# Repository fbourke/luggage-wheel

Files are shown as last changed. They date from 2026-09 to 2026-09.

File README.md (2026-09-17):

# luggage-wheel

Replacement dual-wheel spinner carriage for Rimowa-style luggage: CNC
aluminium body swivelling on the case's Ø10 shaft (needle thrust bearing +
Oilite bushing) and a through-axle carrying two wheels. The original wheels
ran on plain plastic bores and wore out.

Two wheel variants share the body (`WHEEL_SOURCE` env var, default `ots`):
**`ots`** uses bought Ø50 × 12 PU luggage wheels on a Ø6 axle (see
[`docs/wheel_sourcing.md`](docs/wheel_sourcing.md)); **`machined`** is our
turned Al hub on 688 bearings with printed TPU tires, kept as a fallback.

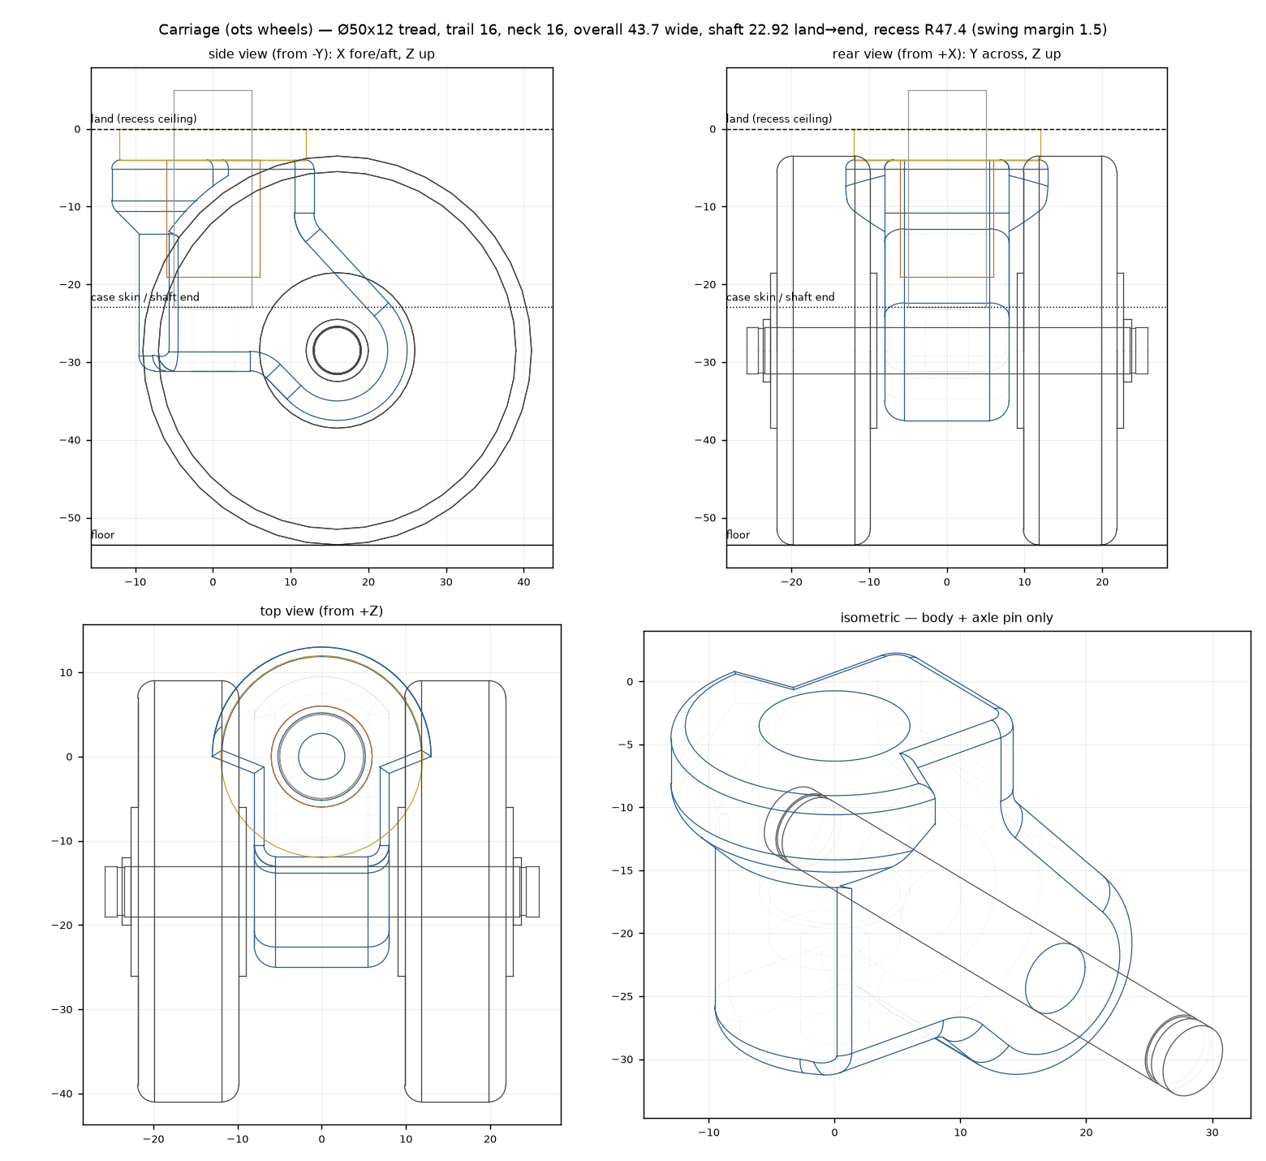
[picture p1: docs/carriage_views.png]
carriage


- [`docs/design.md`](docs/design.md) — envelope, swivel, axle, machinist tolerances, print settings, open questions
- [`docs/wheel_sourcing.md`](docs/wheel_sourcing.md) — off-the-shelf wheel research (Floyd, generic 50×12, Rimowa OEM…)
- [`bom.md`](bom.md) — parts, quantities, sources
- [`cad/params.py`](cad/params.py) — every dimension, single source of truth
- [`cad/wheel.py`](cad/wheel.py), [`cad/carriage.py`](cad/carriage.py) — build123d models
- [`cad/generate.py`](cad/generate.py) — exports + clearance report
- [`cad/preview.py`](cad/preview.py), [`cad/views.py`](cad/views.py) — PNG renders

## Regenerate

Dependencies are managed with [uv](https://docs.astral.sh/uv/).

```sh
uv run cad/generate.py                        # ots: STEP + STL into export/, clearance report
uv run cad/views.py                           # docs/carriage_views.png
WHEEL_SOURCE=machined uv run cad/generate.py  # fallback variant into export/machined/
WHEEL_SOURCE=machined uv run cad/views.py     # docs/carriage_views_machined.png
uv run cad/preview.py                         # docs/cross_section.png (machined wheel)
```

## Outputs

| File | Use |
|---|---|
| `export/body.step`, `axle_pin.step`, `ots_spacer.step` | to the CNC shop, with the tolerance tables in `docs/design.md` |
| `export/ots_wheel_ref.step` | dummy of the bought wheel, for reference |
| `export/carriage_fit_proto.stl` | **one-piece printed fit-check**: body + thrust collar + solid wheels; screws straight onto the case with the existing M5 bolt |
| `export/body_proto.stl` | printed body for bushing/axle fit checks |
| `export/carriage_assembly.step` | full assembly with dummy wheels, for viewing |
| `export/machined/…` | the same set for the machined-wheel variant, plus `hub.step`, `spacer.step`, `tire.step`/`.stl`, `wheel_assembly.step` |

STL files are not committed (regenerate them); STEP files are.

## Status

Envelope fully measured; a printed one-piece proto **fits the recess, pivots
freely and matches the OEM ride height**. Direction is now bought Ø50 × 12
wheels on the machined body. Next: buy a pack, measure them, print
`body_proto.stl`, then order metal. Open questions are in `docs/design.md`.

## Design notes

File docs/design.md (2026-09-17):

# Replacement spinner carriage — design notes

Replacement for a failed dual-wheel spinner carriage (Rimowa-style knockoff):
the whole unit that bolts onto the case's Ø10 swivel shaft and carries two
Ø50 × ~12 mm wheels. The original's wheels ran on plain plastic bores, which
wore out.

carriage

## Two wheel variants, one body

`params.py` has a `WHEEL_SOURCE` switch (environment variable; default `ots`):

- **`ots`** — off-the-shelf Ø50 × 12 dual-spinner luggage wheels (PU tread,
  plastic hub, one Ø6-bore ball bearing, 13.7 over the hub bosses; ~$2.50
  each in 8-packs). Ø6 axle, trail 16. **This is the plan** — see
  [`wheel_sourcing.md`](wheel_sourcing.md) for the research.
- **`machined`** — our turned Al hub on 2× 688 with a printed TPU tire. Ø8
  axle, trail 18.1. Kept as the fallback if the bought wheels disappoint;
  builds into `export/machined/`.

The body is the same part except for the axle bore (Ø6 vs Ø8) and its
position (trail). Everything below applies to both unless it says otherwise;
the "Wheel" chapter is the machined variant.

## Architecture (`ots`)

| Part | Material | Made by | Qty / carriage |
|---|---|---|---|
| Body | Al 6061-T6 | outsourced CNC (3-axis milled) | 1 |
| Axle pin | Ø6 h6 ground steel shaft, 51.6 long, 2 circlip grooves | cut + grooved, or CNC order | 1 |
| Circlip | DIN 471 Ø6 | purchased | 2 |
| Wheel | generic Ø50 × 12 PU luggage wheel, Ø6 bearing | purchased, 8-pack | 2 |
| Inboard spacer bush | Ø8 / Ø6.1 × 1.0, steel or Al (kits include similar) | kit / turned / printed | 2 |
| Outboard ring | steel 6×10×0.5 washer | purchased | 2 |
| Swivel thrust bearing | AXK1024 needle thrust + 2× AS1024 washers | purchased | 1 set |
| Swivel bushing | Oilite SAE 841, 10×12×15 | purchased | 1 |
| Retention bolt | existing M5 button head, 19 under head — bears directly on the body | reuse | 1 |

For `machined` swap the wheel rows for: Ø8 axle pin 46.4 long, DIN 471 Ø8
circlips, 2× Al hub, 4× 688-2RS, 2× Al spacer ring, 4× 8×12×0.5 speed rings,
2× TPU tire.

Everything is parametrised in [`cad/params.py`](../cad/params.py); regenerate
with `uv run cad/generate.py`.

## Coordinate frame

`X` fore/aft with the shaft axis at X = 0 and the wheels at X = +TRAIL (16 for
`ots`, 18.1 for `machined`);
`Y` across; `Z` up with **Z = 0 at the land** — the raised plastic face at the
ceiling of the corner recess that the swivel bears on. The case's bottom skin
is at Z = −22.92, flush with the shaft end; floor at Z = −53.5.

## Envelope — why the body looks the way it does

Each corner of the case has a **quarter-circle recess**, ~47.4 mm radius about
the shaft axis and 22.9 mm deep. The Ø10 shaft hangs from the recess ceiling
and ends flush with the case skin, so the whole shaft, the swivel, and the
upper 19 mm of the wheels live inside the recess; the wheels stick out ~30 mm
below the skin. Measured: land → floor 53.5, so **the wheel top is 3.5 mm
below the land** and the axle is 28.5 mm down. Consequences:

- Nothing can sit above the wheels. Everything that spans wider than the
  **16 mm neck** (wheel gap 17 − 2 × 0.5) has to be in front of the wheel
  circle or sculpted to it.
- **Swivel boss** — a "cap" of revolution about the shaft axis: **Ø26 for the
  top 6 mm** (the band that backs the Ø24 thrust washer), a **45° cone** down
  to a **Ø19 stem** around the bore, running to the **flat at Z −24.6** that
  the bolt head bears on. In plan the cap is a half-round in front, tapering
  into the neck 2 mm behind the axis. The stem gives 3.5 mm of wall over the
  Ø12 bushing bore and encloses the shaft end. Wherever the boss overhangs the
  wheels (|Y| > 8) it is scooped to a cylinder 1.5 mm outside the tire — this
  trims the cap rim ("ears") and cuts the stem flush with the neck faces where
  the wheels pass. Rounds: R2 on the cap underside edge, R1.5 on the top
  perimeter, R2 on the cap corners.
- **Arm**: in side view, a Ø18 round about the axle joined to the boss by two
  tangent lines — one from the boss rear at Z −12 (nothing above it), one from
  the flat just behind the bolt head. Nothing sits under the bolt head.
- The whole body is inside the recess above the skin plane (max 27 mm from
  the axis; the wall is at 47).
- **Width is capped by the recess wall.** The farthest point from the swivel
  axis is the outer tread edge where the wheel crosses the skin plane; the
  original (16.63 gap, 11.5 wheels) swings at R 46.86 against a ~47.4 wall.
  Width and trail trade off against each other: `machined` keeps 11.5 mm
  wheels at the original 18.1 trail (swing R 46.86, overall 39.6); `ots`
  wheels are 13.7 over the bosses so the trail drops to 16.0, which brings the
  swing radius *in* to 45.9 (overall 43.7). `params.py` asserts the swing
  radius never exceeds the original's.

`generate.py` prints an analytic clearance report (thrust washer ↔ tire, neck
↔ tire, wheel swing ↔ recess wall, body and bolt head ↔ floor). Check it
after every parameter change.

## Swivel

The Ø10 (measured 9.82) shaft is fixed to the case; the body rotates on it and
the case's weight bears on the Ø20.4 plastic land molded around the shaft,
with radial ribs at the same height.

**Thrust — AXK1024 needle roller thrust bearing (10×24×2) between two AS1024
hardened washers (10×24×1)**, 4 mm total, between the land and the body's top
face. The upper washer is stationary against the plastic, the lower one turns
with the body, needles between. The Ø24 washer overhangs the Ø20.4 land by
1.8 mm but sits on the ribs there, and spreads the load on the plastic far
better than the old body did.

**Radial — Oilite bronze sleeve bushing 10×12×15**, pressed into a Ø12 H7 bore
from the top, flush with the top face. A swivel turns a few degrees at near
zero speed under moderate load: that is textbook sintered-bronze territory, and
no ball bearing with a Ø10 bore fits inside an 18 mm neck anyway (6800 is
Ø19 OD). Shaft finish matters more than the bushing: if the shaft is rough or
plated-and-chipped, polish it.

**Retention** — OEM style, closed bore, **position-controlled by the bolt
bottoming out**. Measured: the existing M5 × 19 button head bottoms in the
shaft's blind thread (10.5 deep) with its **head underside 8.5 mm below the
shaft end**. That head is the fixed stop the body hangs from, so:

- Ø10.4 shaft clearance bore down to a **step ceiling 0.3 mm *below* the shaft
  end** (Z −23.22) — never touches;
- **7.9 mm of solid aluminium** under that, with a **Ø5.5 hole** for the shank;
- **flat at Z −31.12**, i.e. 0.3 mm above the bottomed head (Z −31.42).

Rolling, the case weight goes land → thrust stack → body and the flat rides
0.3 above the head; lift the case and the body drops 0.3 onto the head. The
bolt is tightened to bottom, not to clamp — there is nothing to clamp against
and clamping would preload the needle bearing. No washer; shaft end captured.
A 3 mm hex key reaches the bolt from below between the wheels.

`BOLT_STICKOUT = RETAIN_BOLT_L − 10.5` in `params.py`: a shorter **M5 × 16**
bolt would bottom with 5.5 exposed and shorten the stem by 3 mm (≈ −3 g);
M5 × 14 → 3.5. The default keeps the OEM bolt.

Earlier revisions had the step 2 mm thick with the ceiling 0.3 mm *above* the
shaft end — both wrong: the shaft would have bottomed on the step and the
bolt could never have reached the flat. The printed proto with that geometry
sat loose by ~6.5 mm on the bolt, which is what flagged it.

## Wheel axle — single through-pin

One **ground steel pin** (Ø6 h6 for `ots`, Ø8 h6 for `machined`) through the
body with a **DIN 471 circlip** at each end. Stack, from the body outward on
each side:

```
ots:      body | spacer bush 1.0 | wheel 13.7 (bosses + bearing) | ring 0.5 | 0.3 float | circlip | 1.5 stub
machined: body | speed ring 0.5  | hub 11.5 (2× 688 + spacer)     | ring 0.5 | 0.3 float | circlip | 1.5 stub
```

For `ots` the inboard bush is a small flanged tube that seats in the wheel's
bearing inner race and holds the rotating plastic hub boss off the body face
(the Amazon kits include these). Ø6 pin bending stress at full corner load is
~60 MPa — fine for any steel.

Why not two shoulder screws: M6×Ø8 shoulder screws from opposite sides each
need ~9.5 mm of thread and would collide inside a 16 mm body. The pin has no
threads, is trapped by the wheels which are trapped by the circlips, and a
wheel comes off by popping one clip. Fix the pin in the body with Loctite 638
(or leave it floating — it cannot go anywhere). A small printed cap can hide
each circlip.

Speed rings guarantee the inner races, not the outer races or hub faces, touch
the body and the circlips.

## Body — tolerances for the machinist

| Feature | Nominal | Tolerance | Why |
|---|---|---|---|
| Bushing bore | Ø12 H7 (+0 / +0.018) | — | Oilite press fit; bushing closes ~0.02 on its ID when pressed, which is what gives the running fit on the Ø10 shaft |
| Bushing bore ⟂ to top face | — | ≤ 0.03 over 15 mm | swivel axis must be square to the thrust washer |
| Axle bore | Ø6.00 (`ots`) / Ø8.00 (`machined`) | +0.005 / +0.015 | light slip fit for an h6 pin, Loctite 638 |
| Axle bore ⟂ to the Y faces of the neck | — | ≤ 0.02 | wheels must run parallel |
| Neck width | 16.0 | ±0.05 | sets wheel gap |
| Step ceiling (bottom of Ø10.4 bore) | 19.22 below the top face | ±0.1 | 0.3 clear of the shaft end; deeper is harmless |
| Boss bottom flat | 27.12 below the top face | **±0.05** | sets the 0.3 lift float against the bottomed bolt head; too far and the body rattles, too close and the head lifts the thrust stack |
| Bolt hole | Ø5.5 through the step | ±0.1 | M5 shank clearance |
| Shaft clearance bore | Ø10.4 | ±0.1 | must never touch the Ø9.8 shaft |
| Everything else | as STEP | ±0.1 | — |

Finish: as-machined or bead-blast + anodise. **Break all edges 0.3–0.5** (not
modelled).

## Body — DFM notes

- **Setups (3-axis mill):** (1) side, Y−: neck side profile, arm rounds,
  axle bore, wheel scoop (a Ø26.5 concave about the axle — ball or bull-nose
  mill, or leave it as a 3D-surfaced pass); (2) side, Y+: mirror; (3) top,
  Z+: boss plan profile, Ø12 H7 bushing bore, Ø10.4 clearance bore to the
  step, top round; (4) bottom, Z−: bottom flat, Ø5.5 bolt hole. A shop will
  likely do 1+2 as one op with a flip and 3+4 likewise. Stock: 30 × 40 × 50.
- **Internal corners** where the arm meets the flat and the boss rear are **R3**
  (`ARM_INNER_R`) — bigger than any sensible tool radius, and it's the only
  stress riser on the part (the arm is a cantilever off the boss).
- **Rounds** are cosmetic and can be dropped or shrunk without telling us:
  arm outline R2.5 (`ARM_EDGE_R`, leaves 11 mm flat on the 16 mm neck), cap
  underside R2, boss top perimeter R1.5, cap corners R2. If the shop quotes
  the rounds as expensive, delete them — chamfer 0.5 instead.
- **The cap cone and stem** are turned-style features on a milled part: a 45°
  chamfer mill from below, or 3D-surfaced. Cheap either way. The stem radius
  (`STEM_R`) must stay > 9 so it meets the neck faces at a healthy angle —
  at ~8.25 it grazes them tangentially, which is bad for both the cutter and
  the CAD kernel.
- **Modelling note:** in build123d `Part.intersect()` returns a `ShapeList`;
  use `&` (see `make_body`). Silent no-op booleans on a ShapeList cost an
  afternoon here.
- **Critical features only:** Ø12 H7 bore and its squareness to the top face,
  the step depth (±0.05, sets the shaft float), neck width ±0.05, axle bore
  fit and parallelism. Everything else ±0.1.
- **Thin spots:** 2 mm between the Ø12 bushing bore and the neck faces; 2 mm
  step under the shaft end; 1.5 mm minimum on the boss "ears" over the wheels.
  All fine in 6061 but don't let anyone "clean up" the neck faces.
- **Material:** 6061-T6. 7075 is pointless here; 6082 is the EU equivalent.
- **Quantity 4** — ask for all four in one setup on a single bar of stock.

# Wheel (`machined` variant only)

Fallback if the bought Ø50 × 12 wheels turn out badly. Skip this chapter for
the `ots` build.

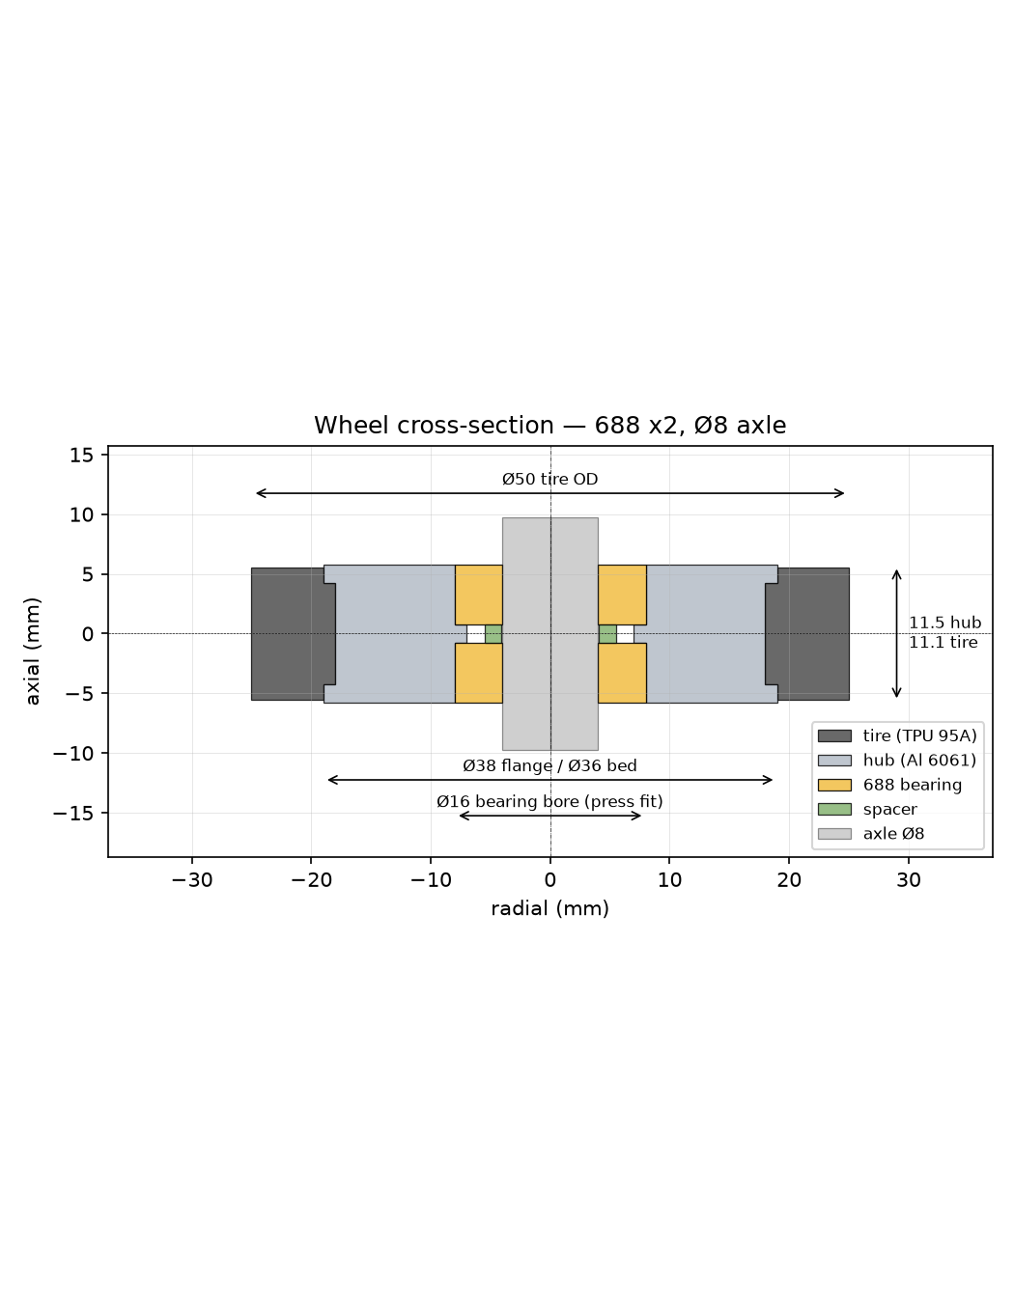
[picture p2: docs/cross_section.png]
wheel cross-section


## Why two bearings per wheel

Each wheel hangs off the side of the body on the axle pin. A single bearing
would let it rock under side load (which is what killed the plastic bore). Two
688s (8×16×5), one at each face of the 11.5 mm hub, give a 6.5 mm span between
bearing centres and turn the rocking load into a simple radial couple.
Load-wise a 688 is still heavily over-rated (Cr ≈ 1.1 kN each; a wheel sees
< 150 N). The 11.5 mm wheel width is forced by the recess (see Envelope): a
608 (7 wide) would only fit singly, and 2× 688 is the widest pair that fits
with a shoulder between them.

Use **2RS** (rubber sealed) variants — the wheel lives at ankle height in grit
and rain. Alternatives are in the `BEARINGS` table in `params.py`.

SKF abutment limits for 688: housing shoulder ≤ Ø14.6, shaft shoulder ≥ Ø9.4.
Design uses a Ø14.0 shoulder and Ø11 spacer.

## Hub — tolerances for the machinist

The hub is a lathe-only part. Callouts that matter:

| Feature | Nominal | Tolerance | Why |
|---|---|---|---|
| Bearing bore (×2) | Ø16.00 | **−0.008 / −0.016** (i.e. Ø15.984–15.992) | light press fit for a 688 (OD 16 h0/−0.008). Bearing goes in with a vise or arbor press, no retaining compound needed. |
| Bore concentricity, both ends | — | ≤ 0.02 TIR | both bearings must share an axis or the wheel binds |
| Shoulder Ø14 | Ø14.0 | ±0.1 | non-critical, just clears the seal |
| Shoulder width | 1.50 | ±0.05 | sets bearing spacing; spacer is matched |
| Hub width (face to face) | 11.50 | ±0.05 | sets the axle stack length |
| Ø38 / Ø36 | — | ±0.1 | tire is stretch-fit, forgiving |
| Chamfers | 0.5 × 45° | — | bore chamfer is the press lead-in, don't omit |

Finish: as-machined is fine. Anodise optional (looks good, no functional need).

If the shop asks for a drawing rather than "STEP + this table", the table above
is the drawing.

## Spacer

Ring Ø11 / Ø8.2 × 1.50 between the inner races — effectively a thick shim
washer. Its length must equal the shoulder width to within ±0.05 so that any
axial load goes through the two inner races and the spacer, **not** the outer
races through the shoulder. Too thin to print well; order it in aluminium with
the hubs (trivial add to the CNC order) or stack 8×11 shim washers to 1.5.

## Speed rings

8×12×0.5 steel washers on both sides of each hub. Their OD (12) touches only
the inner race (Ø8–12.1), so the body face and the circlip bear on the inner
races and never drag on the outer race or the hub face.

## Tire

- TPU 95A (e.g. NinjaFlex Cheetah, Polymaker TPU95, Overture TPU). Softer
  (85A) rolls quieter but wears faster and prints worse.
- Modelled **1.5 % undersize** on the ID so it stretches onto the Ø36 bed and
  snaps over the Ø38 flanges. It has to be stretched over a Ø38 flange to
  install (≈ 7 % strain at the lip) — trivial for TPU. Warm water helps.
- Two flanges capture it axially; friction + stretch handle torque. If it ever
  creeps, a thin smear of CA on the bed fixes it permanently.
- Print orientation: **flat on its side** (axis vertical), so layer lines run
  circumferentially — that's the quiet orientation and the strong one.
- Print settings that matter: 100 % infill (or ≥ 4 walls + gyroid ≥ 40 %),
  slow (20–30 mm/s), retraction minimal, dry filament. Tread will be slightly
  slick when new; it scuffs in.
- Minimum wall is 6 mm over the flange. Below ~4 mm TPU starts to feel like
  riding on the aluminium.

# Prototype sequence

1. ~~Measure the open questions~~ — done 2026-09-15.
2. ~~Print `carriage_fit_proto.stl` and screw it on~~ — done 2026-09-16 with
   the 11.5-wide/18.1-trail geometry: fits, pivots freely, ride height matches
   the other corners. The `ots` geometry (13.7 wheels, trail 16) swings
   *inside* that envelope, so it doesn't need its own fit check.
3. **Buy an 8-pack of Ø50 × 12 PU luggage wheels** (e.g. Amazon B0DLNMPGF9,
   ~$20) and measure them: OD, tread width, width over the bosses, bore, boss
   diameter. Update `OTS_*` in `params.py` if they differ from 50 / 12 / 13.7 /
   6 / 20. Spin one on a Ø6 pin: if the bearing feels gritty or the wheel rocks
   noticeably, that's the cue to fall back to `machined`.
4. Print `body_proto.stl` (PETG, 100 % infill) with the real Ø6 axle bore and
   trail; ream the Ø6 and Ø12 bores to a slip fit. Mount the bought wheels on
   a 6 mm pin (or the kit's own axle) and check the wheel ↔ boss scoop and
   thrust-washer gaps in the flesh.
5. Buy the rest: AXK1024 + 2× AS1024, Oilite 10×12×15, Ø6 h6 precision shaft
   (or a 6 mm dowel pin ≥ 55 long), 2× DIN 471 Ø6 circlips, 6×10×0.5
   washers — or just use the wheel kit's axle + screw, which fit.
6. Assemble on the case. Check: wheel ↔ recess ceiling, swing through 360°,
   thrust washer ↔ tire, body ↔ tire, swivel free under load, lift retention,
   case level.
7. Adjust → regenerate → send `body.step` + `axle_pin.step` (+ the spacer
   bushes if the kit's don't suit) with the tolerance tables to a CNC shop.
   Four of each; the other three corners will fail the same way.
8. For the `machined` fallback: `WHEEL_SOURCE=machined uv run cad/generate.py`,
   then hubs/spacers/pins from `export/machined/`, 688s, printed TPU tires.

# Open questions

Measured 2026-09-15 (all now in `params.py`):

- [x] Land → shaft end 22.92; shaft end flush with the case skin; shaft Ø9.82.
- [x] Land Ø20.39, raised, with radial ribs at the same height (backs the Ø24
      thrust washer).
- [x] Retention bolt: M5 button head, 19 under head.
- [x] Original wheels 11.5 wide, gap 16.63, ~40 overall.
- [x] Corner recess: quarter circle, wall ~42.4 from the shaft OD (R ≈ 47.4).
- [x] All four carriages eventually.

Test-fit 2026-09-16 (blocky body, 11.5 wheels, trail 18.1): fits the recess,
pivots perfectly, height matches the OEM corners.

Still open:

- [ ] Actual dimensions of the bought Ø50 × 12 wheels (see prototype step 3).

- [x] Recess radius: the printed proto swings a full 360° at swing R 46.86;
      the `ots` geometry swings at 45.9.
- [ ] Is the recess wall vertical, or does it flare? (Only matters if we ever
      want wider wheels.)
- [ ] Shaft surface: plain steel? chrome? any wear from the old plastic bore?
      Oilite 10 mm ID on a 9.82 shaft is ~0.2 mm loose — acceptable for a swivel,
      but if it feels sloppy, a 3D-printed or bronze 9.9 ID sleeve is the fix.
- [ ] Bolt thread pitch: M5×0.8 assumed (standard coarse).

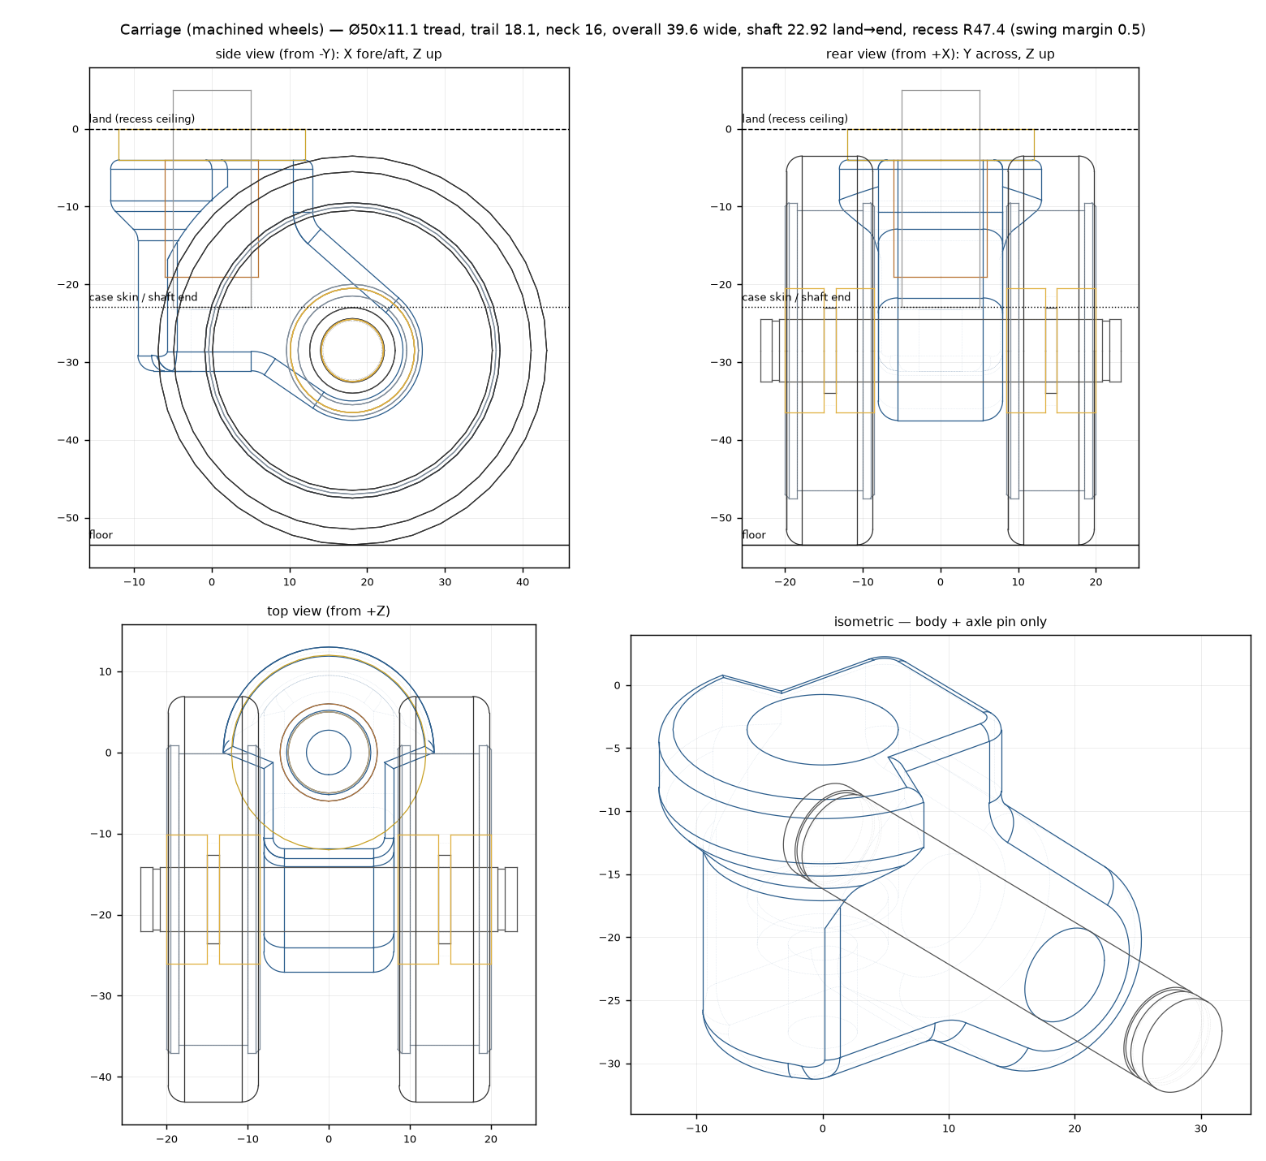
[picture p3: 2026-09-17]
docs/carriage_views_machined.png

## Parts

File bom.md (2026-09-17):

# Bill of materials

Per carriage (one corner, two wheels), and for all four corners. This is the
**`ots` build** (bought Ø50 × 12 wheels); the machined-wheel fallback is at the
bottom.

## Machined (send STEP + tolerance tables from `docs/design.md`)

| # | Item | File | Material | Per carriage | ×4 | Est. cost (×4) |
|---|---|---|---|---|---|---|
| 1 | Body | `export/body.step` | Al 6061-T6, 3-axis milled | 1 | 4 | $120–240 |
| 2 | Axle pin | `export/axle_pin.step` | steel, Ø6 h6 × 51.6, two DIN 471 grooves | 1 | 4 | $20–40, or cut from 6 mm precision shaft and groove by hand/Dremel |
| 3 | Inboard spacer bush | `export/ots_spacer.step` | steel or Al, Ø8 / Ø6.1 × 1.0 — only if the wheel kit's bushes don't fit | 2 | 8 | $10 |

Services: PCBWay / JLCCNC / Xometry / Protolabs, or a local shop. One quote for all line items — setup dominates at these quantities.

## Purchased

| # | Item | Spec | Per carriage | ×4 | Source | Est. (×4) |
|---|---|---|---|---|---|---|
| 4 | **Wheel** | generic **Ø50 × 12 mm PU luggage replacement wheel**, Ø6 bearing bore, ~13.7 over the hub bosses. e.g. Amazon B0DLNMPGF9 (FLIHONST, PU) — avoid TPE-tread listings. Kits include Ø6 axles, screws, washers, spacer bushes, Ø42 caps. | 2 | 8 | Amazon / AliExpress, 8-packs | **$20–25** (one pack) |
| 6 | Circlip | **DIN 471 Ø6** external retaining ring (groove Ø5.7 × 0.8) | 2 | 8 | hardware / McMaster | $3 |
| 7 | Outboard rings | 6 mm ID × 10 OD × 0.5 steel washers (DIN 988 shim rings) | 2 | 8 | McMaster / Amazon shim assortment | $5 |
| 8 | Thrust bearing | **AXK1024** needle roller thrust, 10×24×2 | 1 | 4 | bearing supplier / Amazon / AliExpress | $8–12 |
| 9 | Thrust washers | **AS1024** hardened, 10×24×1 | 2 | 8 | same, often bundled with AXK1024 | $5–8 |
| 10 | Swivel bushing | **Oilite SAE 841 sleeve, 10 ID × 12 OD × 15 L** | 1 | 4 | McMaster 6391K-series / bearing supplier | $6–10 |
| 12 | Retention bolt | existing — reuse; head bears directly on the body (closed bore, no washer). If replacing: M5×0.8 button head (ISO 7380) × 20, + blue Loctite | 1 | 4 | — | $0 |
| 13 | Retaining compound | Loctite 638 (axle pin in body) | — | 1 tube | — | $10 |

## Printed

| # | Item | File | Material | Per carriage | ×4 |
|---|---|---|---|---|---|
| 15 | Circlip cap (optional; the wheel kits' Ø42 snap caps may do) | — | any | 2 | 8 |
| — | One-piece fit proto | `export/carriage_fit_proto.stl` | PETG or PLA, ~75 g, supports on | 1 | — |
| — | Body proto | `export/body_proto.stl` | PETG, 100 % infill | 1 | — |

**Rough total for four corners: $220–380**, dominated by the milled body. One corner only: ~$100–150 (small-quantity CNC pricing hurts).

## Machined-wheel fallback (`WHEEL_SOURCE=machined`, files in `export/machined/`)

Replaces items 2–4, 6, 7 above: Ø8 h6 × 46.4 axle pin with DIN 471 Ø8 grooves
($20–40 ×4); 2 Al hubs per carriage (`hub.step`, $60–120 ×4); 2 Al spacer
rings (`spacer.step`, $10–20); 4× **688-2RS** 8×16×5 bearings per carriage
($10–20 for 16); DIN 471 Ø8 circlips; 8×12×0.5 skate speed rings; 2 printed
TPU 95A tires (`tire.stl`, ~12 g each, on their side, 100 % infill). Adds
~$100–200 to the four-corner total.

## Tools

- (machined variant only) bench vise or arbor press + a socket that bears on the 688 outer race
- 3 mm hex key (retention bolt head is exposed under the boss, reached from below between the wheels)
- Circlip pliers (external, small)
- Digital calipers
- Optional: 8 mm and 12 mm reamers for the printed prototypes

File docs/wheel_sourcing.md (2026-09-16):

# Wheel sourcing — off-the-shelf options

Research notes, 2026-09-16. Goal: stop making our own wheels (Al hub + printed
TPU tire) and buy a professionally moulded PU wheel instead. Hard constraints
from the case (see `design.md`, "Envelope"):

| Constraint | Value | Why |
|---|---|---|
| Diameter | 50 (47–52 tolerable if all four corners are done) | ride height must match the other corners |
| Width per wheel | ≤ ~12.5 tread, ≤ ~14 over any hub bosses | recess wall caps the swing radius at ≈ 47 mm |
| Bore | anything — we make the axle | — |
| Bearings | ball bearings strongly preferred | the plain plastic bore is what failed |

## Shortlist

| # | Product | OD × width | Bore / bearing | Tread | Price / wheel | Fit | Verdict |
|---|---|---|---|---|---|---|---|
| 1 | **Generic "50 × 12 mm luggage replacement wheel" 8-packs** (Amazon B0DLNMPGF9 — FLIHONST; many identical listings) | Ø50 × 12 tread, **13.7 over the hub bosses** | Ø6, one ball bearing in a PP hub, flanged spacer bushes each side | PU | **$2.50** ($20 / 8, incl. axles, screws, washers, Ø42 caps, hex keys) | **Drop-in** with a Ø6 axle | **Buy one pack now.** Exactly the OEM format. |
| 2 | Zoofen 50 × 12 8-pack (Amazon B0CTDM5851) | Ø50 × 12, 14 overall | Ø6, one bearing | **TPE** (softer, wears faster) | $3 | drop-in | Skip in favour of #1 (PU). |
| 3 | Floyd wheel set (floyd.one) | **Ø55 × ~19** (55 and 85A printed on the wheel; width measured from a photo of Floyd's rear carriage — 31 px against 89 px of diameter, an upper bound) | 608 skate bearings ×2, skate axle + nut | PU 85A, made in China | $9.40 ($75 / 8) | ✗ dual (needs trail ≤ 11) · ✓ **single centred wheel** | The narrowest 55 mm skate-type wheel we found. Needs a fork body — see below. |
| 4 | Aggressive-inline 55 mm wheels: IQON EQO 55/88A (proskatersplace.com), Ground Control Moon 55/92A (intuitionskate.com); also Undercover, Eulogy, Dead in 55–58 | **Ø55 × 24** (stated) | 608 ×2 (+ standard 8 mm bearing spacer) | cast PU 88–92A | $9–11 ($36–45 / 4) | ✓ single only | Real skate-grade urethane, many brands, any skate shop. 88A is the quieter end; 92A is hard. |
| 4b | Soft skateboard/cruiser 55 mm wheels (OJ, Ricta Clouds, Bones ATF…) 78–85A | Ø55 × 30–35 | 608 ×2 | PU 78–85A | $8–10 | ✓ single, fork gets ~48 wide | Quietest urethane, but chunky. |
| 4c | Generic "55 mm luggage replacement wheel" 8-packs (Amazon B0DM7HD933 etc.) | Ø55 × 12, ~13.7 over bosses | Ø6, one bearing | PU/TPU | $2.50 | ✓ dual at trail ≤ 15, +4.5 mm ride height | The 55 mm version of #1, if you'd rather go up a size. |
| 5 | Rimowa OEM replacement wheels (Topas / Classic / Original / Salsa carry-on) | **Ø47** ("1.85 in"), width not listed | not listed | PU | **$53** ($212 / 4) | −1.5 mm ride height | Overpriced for what it is; Rimowa's own dual wheel is just a nicer #1. |
| 6 | Hinomoto (JP OEM: Rimowa Essential, Tumi, Proteca, Monos) | — | — | — | — | — | See "premium thread" below; Hinomoto sells caster *units* to brands, not bare wheels at retail, as far as we could find. |

## What Floyd actually sells

The Floyd "wheel set" is eight **55 mm, 85A** urethane wheels with two ABEC‑7
(608) bearings each, "designed and developed for Floyd cases only", made in
China. The product photos show a plain skate-wheel profile with the bearing
face exposed, a hex axle nut and a skate-style ratchet tool. In other words
it's a narrow skate wheel with Floyd's graphics, and the $75 is brand +
colourway. The width isn't published; measuring a product photo of Floyd's
rear carriage edge-on (31 px wide vs 89 px tall, and any viewing angle can
only make it look *wider*) gives **≈ 19 mm** — narrower than aggressive-inline
wheels (24) and much narrower than street skate wheels (30–34).

Floyd's carriage is a **fork**: two wheels on a through-axle with a ~30 mm
neck between them, ~68 mm overall. Their case's corner recess is built for
that; ours (R ≈ 47) is not.

## Dual vs single at 55 mm — the numbers

The recess caps the swing radius at the original's 46.86 (wall ≈ 47.4). For a
wheel of radius r whose axle sits `dz` below the skin plane, the tread crosses
the skin at `x = trail + √(r² − dz²)`, and the swing radius is
`hypot(x, half-width)`. Raising the case (lower axle) shrinks the chord, but
slowly:

| Wheel | Layout | Half-width | Ride height | Max trail |
|---|---|---|---|---|
| 55 × 19 | dual (neck 16 + 1 mm spacers) | 28.0 | +4.5 | **11.1** |
| 55 × 19 | dual | 28.0 | +9.5 | 13.1 |
| 55 × 19 | **single, centred** | 9.5 | +4.5 | **19.5** |
| 55 × 24 | single, centred | 12.0 | +4.5 | 18.9 |
| 55 × 32 | single, centred | 16.0 | +4.5 | 17.6 |
| 50 × 12 (bought, `ots`) | dual | 21.85 | 0 | 17.4 (we use 16) |

So a dual of 55 × 19 would need trail ≈ 11 (0.2 D — a caster that short
flutters), and every extra 5 mm of ride height only buys ~1 mm of trail.
A **single centred 55 mm wheel keeps the full 18 mm trail** at +4.5 mm ride
height, for any width up to ~30. That's the route for Floyd or skate wheels.

## Why generic 50 × 12 wins

The case was designed around this exact wheel: Ø50, 12 tread, ~14 over the
hub bosses, Ø6 axle, snap caps. The dozens of 8-pack kits on Amazon are the
same moulding family (the marketing images even show the 11.5–19.5 mm fork
slot they fit). What they are not is *good*: a single small bearing in a PP
hub, so the wheel can rock a little on the axle, and tread quality varies by
listing. That's still far better than the plain bore that failed, and at
$2.50 a wheel they're consumables — keep the other four from the pack as
spares.

The **carriage variant for these wheels** is the default in `params.py`
(`WHEEL_SOURCE=ots`):

- Axle pin Ø6 h6 × 51.6 with DIN 471 Ø6 circlips (groove Ø5.7 × 0.8).
- Neck 16 as before; a flanged Ø8 × 1.0 spacer bush between each body face and
  the wheel's bearing inner race, so the plastic hub boss never rubs the body.
- **Trail 16.0** (was 18.1). The pair is 2.2 mm wider than the originals over
  the tread, so the axle moves 2.1 mm forward to keep the swing radius inside
  the original's (45.9 vs 46.86; wall ≈ 47.4). 0.32 D is still plenty of
  caster trail.
- Overall width 43.7 over the tread; 39.6 for the machined variant.

`WHEEL_SOURCE=machined uv run cad/generate.py` still builds the Al-hub design
into `export/machined/`.

## Single-wheel fork — if you want skate wheels

A single Ø55 wheel centred under the swivel:

- Wheel top 3 mm below the land → axle at Z −30.5, **ride height +4.5 mm** at
  every corner (so all four carriages, no mixing with OEM corners).
- Trail stays at 18 (see table above).
- Body becomes a **fork**: Ø26 swivel boss in front as now, then two 5 mm arms
  either side of the wheel — 31 wide at the axle for a 19 mm wheel, 36 for a
  24 mm wheel, ~44 for a 32 mm cruiser wheel. Arm rear corners swing at R ≈
  31–35, far inside the wall. Or a Floyd-front-style cantilever (one arm,
  wheel outboard on a stub axle with a nut) — simpler to machine, asymmetric,
  and the wheel flips sides as you change direction.
- Axle: Ø8 skate standard, 608 ×2 with the standard 10 mm skate bearing
  spacer, an M8 shoulder bolt with a nyloc, or a Ø8 pin + circlips as now.
- Wheel choice: Floyd 55 × 19 85A ($9.40, buy 8 get 4 spares) or any
  aggressive-inline 55 × 24 (88A for quiet, $9–11). Street/cruiser skate
  wheels work too but make a wide fork.

This is a new body (~a day of CAD, `WHEEL_SOURCE=single55`) and a different
look. Parked unless you want it.

## Premium thread — unresolved leads

Not run to ground: every search engine we could reach ended up captcha- or
rate-walled partway through the evening. What we know and what's worth ten
minutes of manual searching:

- **Hinomoto** (Japan) is the OEM behind Rimowa Essential, Tumi, Proteca,
  Monos and others, and the only luggage-wheel brand people ask for by name.
  Everything we saw is sold as complete *caster units* to brands; the Amazon
  "Hinomoto" search results are generic look-alikes. Worth trying: Amazon JP /
  Rakuten for `スーツケース 交換 車輪 50mm ベアリング` (suitcase replacement
  wheel 50 mm bearing) — the Japanese-market kits tend to be a grade above the
  US Amazon ones, same format. Also Hinomoto's own site for a parts list.
- **Rimowa Essential** (post-LVMH) dual wheels: Reddit threads say they differ
  from the older 47 mm wheels, but nobody quotes dimensions. If a repair shop
  sells them bare they would be the premium version of #1; expect ~$15–25 each.
- **PU-coated bearing rollers**: industrial guide rollers exist as a bearing
  (688 / 6000 / 6001) overmoulded with a PU tyre, typically Ø30–60 × 10–16.
  A Ø50 × 12 on a 688 or 6000 would be a near-ideal wheel — steel hub, real
  bearing, moulded PU — and would justify a dedicated axle. Search
  AliExpress/Misumi for "PU coated bearing 50mm", "polyurethane roller
  bearing 8x50x12", "6000 PU wheel 50mm". Unverified.

## Dead ends

- Inline-skate anti-rocker/grind wheels: Ø42–47 but 24 wide.
- Skateboard / roller-skate wheels: Ø50–60 but 30+ wide (fine as singles).
- Nothing at Ø55 narrower than Floyd's ~19 turned up; 55 × 19 looks like a
  Floyd-specific mould.
- Casters with Ø50 PU tread: 18–20 wide, plain bores.
- DuckDuckGo (captcha), Bing (junk results), Reddit and Amazon product pages
  (block fetches) were unusable for automated research; Brave search worked.

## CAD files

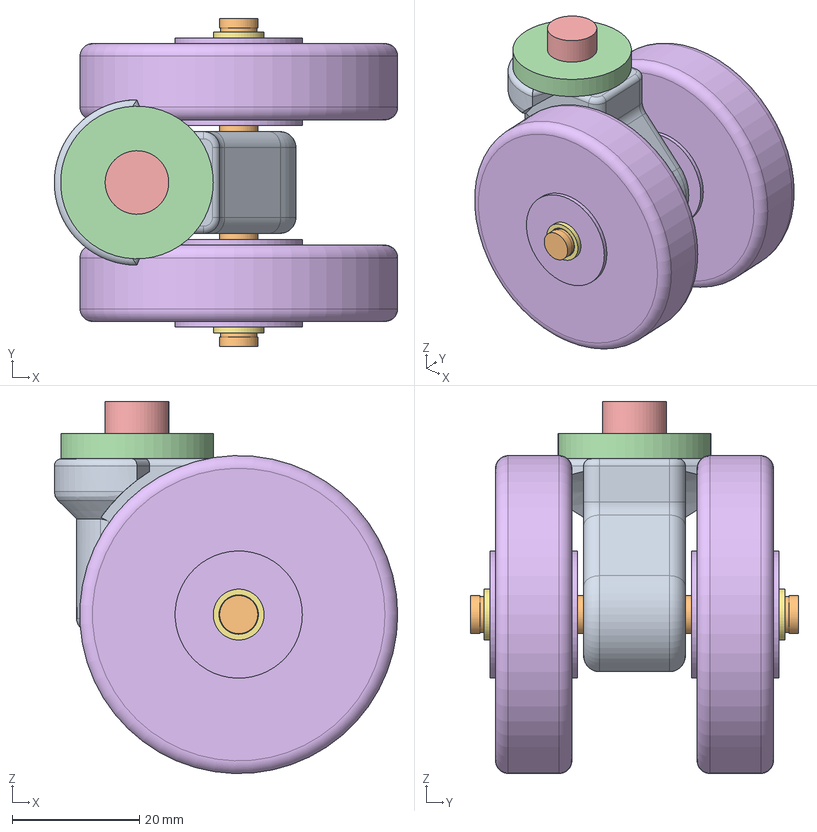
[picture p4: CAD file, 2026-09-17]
export/carriage_assembly.step
54.0 x 51.6 x 58.5 mm
axle_pin
bushing
thrust_AXK1024
case_shaft_ref
ots_wheel_R x 2
spacer_R x 2

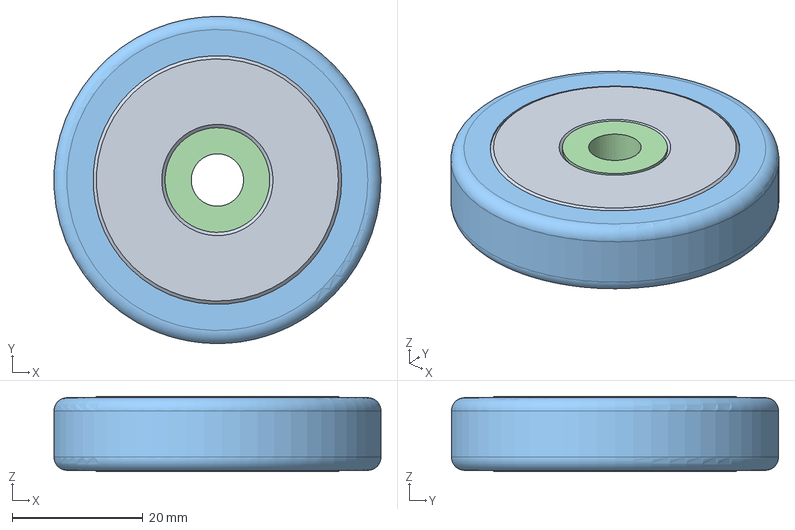
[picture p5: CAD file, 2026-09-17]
export/machined/wheel_assembly.step
50.0 x 50.0 x 11.5 mm
hub
spacer
tire
bearing_inner x 2

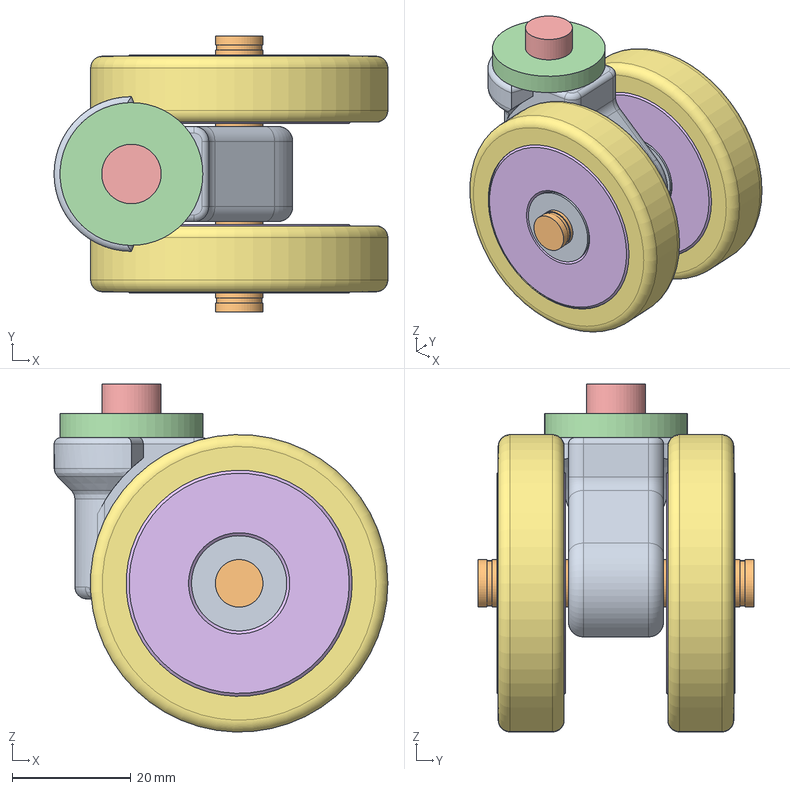
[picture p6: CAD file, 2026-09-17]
export/machined/carriage_assembly.step
56.1 x 46.4 x 58.5 mm
axle_pin
bushing
thrust_AXK1024
case_shaft_ref
hub_R x 2
tire_R x 2
spacer_R x 2
bearing_R_inner x 4

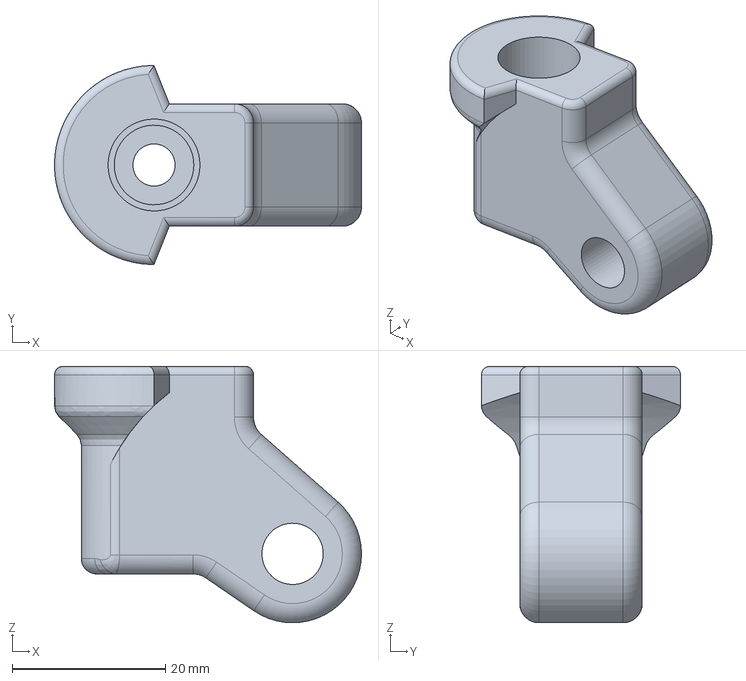
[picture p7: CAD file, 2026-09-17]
export/machined/body.step
40.1 x 26.0 x 33.5 mm

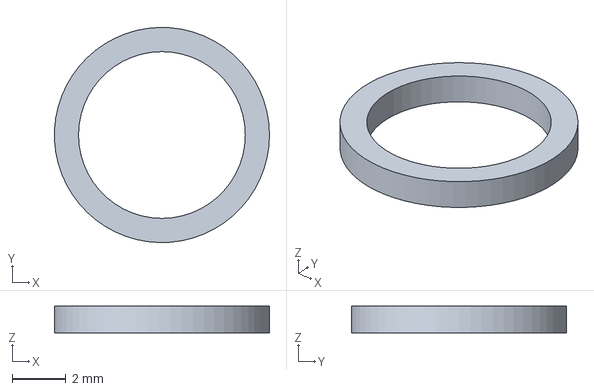
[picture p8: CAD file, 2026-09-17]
export/ots_spacer.step
7.99 x 8.00 x 1.00 mm

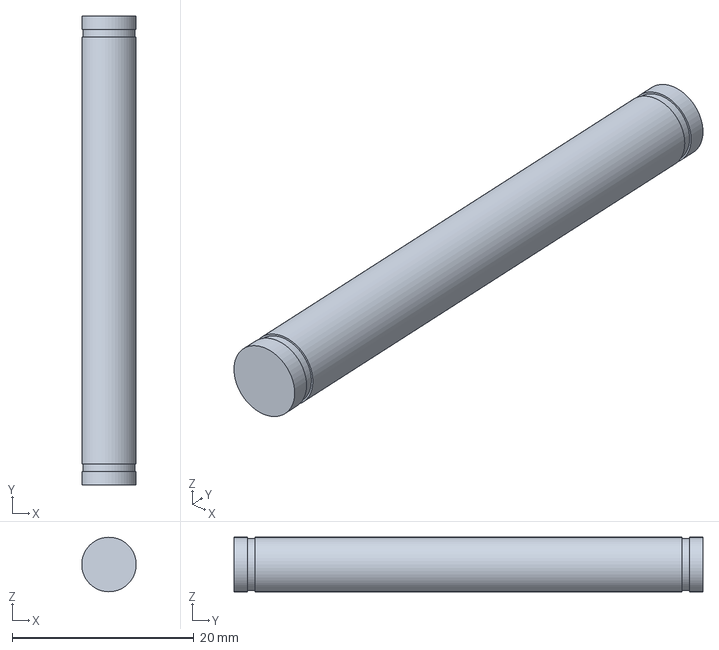
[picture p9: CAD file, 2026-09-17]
export/axle_pin.step
5.99 x 51.6 x 6.00 mm

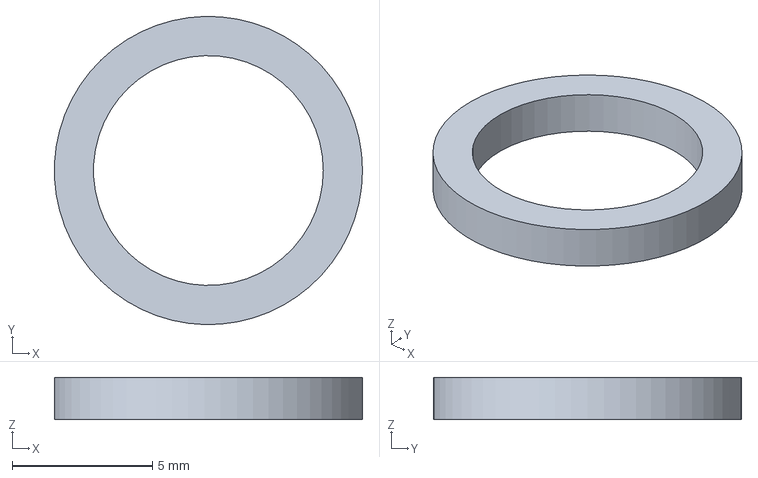
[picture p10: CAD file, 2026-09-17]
export/machined/spacer.step
11.0 x 11.0 x 1.50 mm

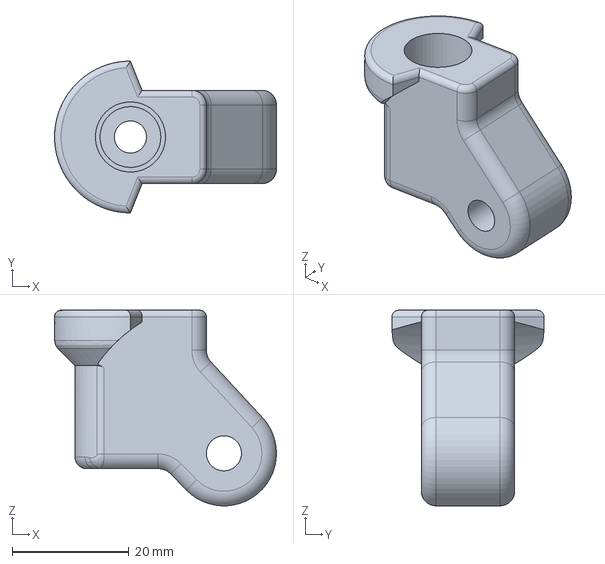
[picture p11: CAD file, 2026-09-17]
export/body.step
38.0 x 26.0 x 33.5 mm

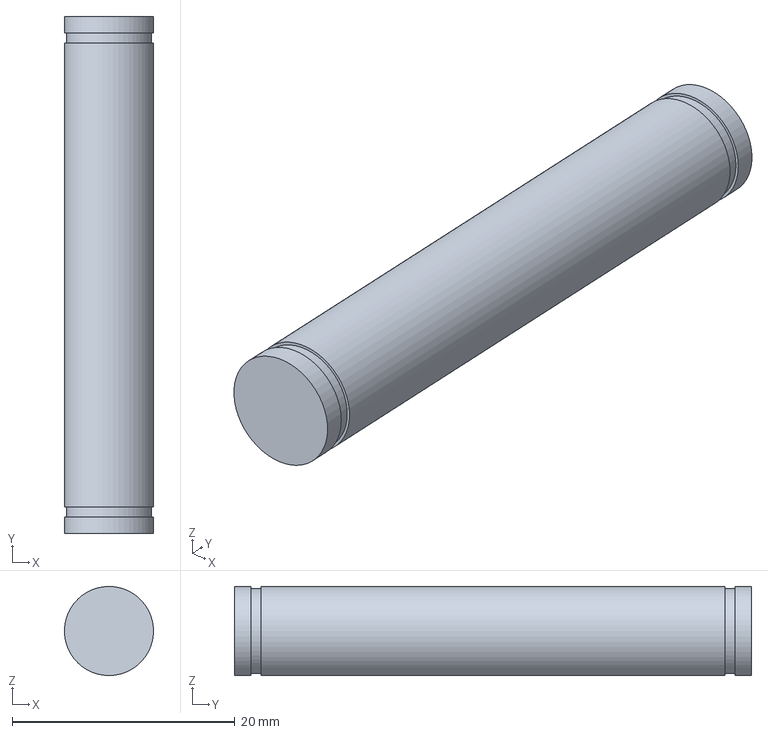
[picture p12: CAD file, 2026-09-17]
export/machined/axle_pin.step
7.99 x 46.4 x 8.00 mm

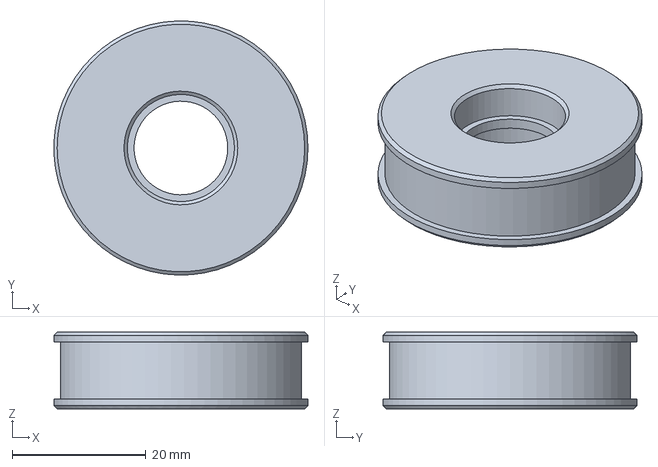
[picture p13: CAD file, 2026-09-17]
export/machined/hub.step
38.0 x 38.0 x 11.5 mm

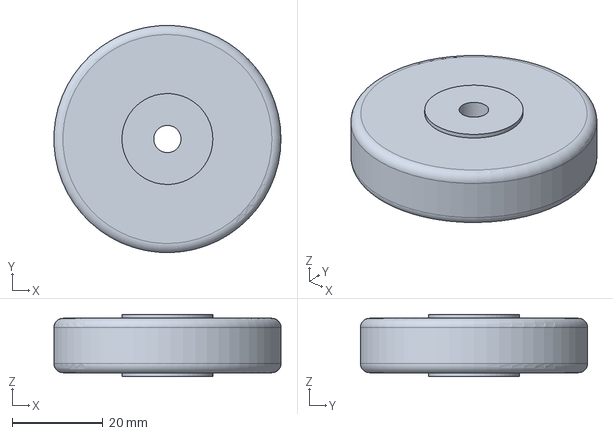
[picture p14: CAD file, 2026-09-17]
export/ots_wheel_ref.step
50.0 x 50.0 x 13.7 mm

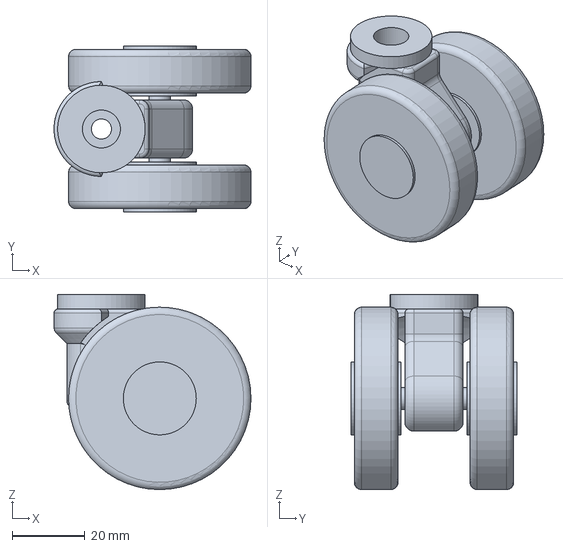
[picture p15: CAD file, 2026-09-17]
export/carriage_fit_proto.step
54.0 x 45.4 x 53.5 mm

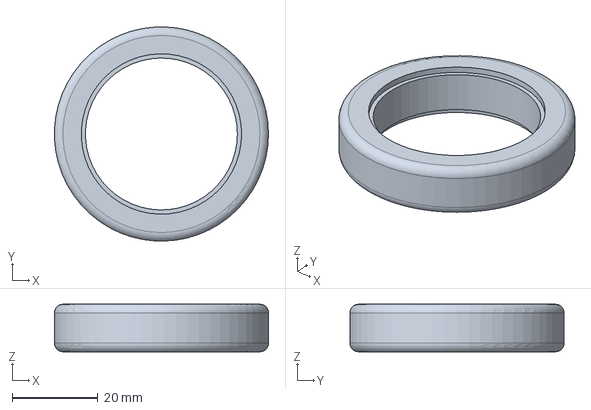
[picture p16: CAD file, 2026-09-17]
export/machined/tire.step
50.0 x 50.0 x 11.1 mm

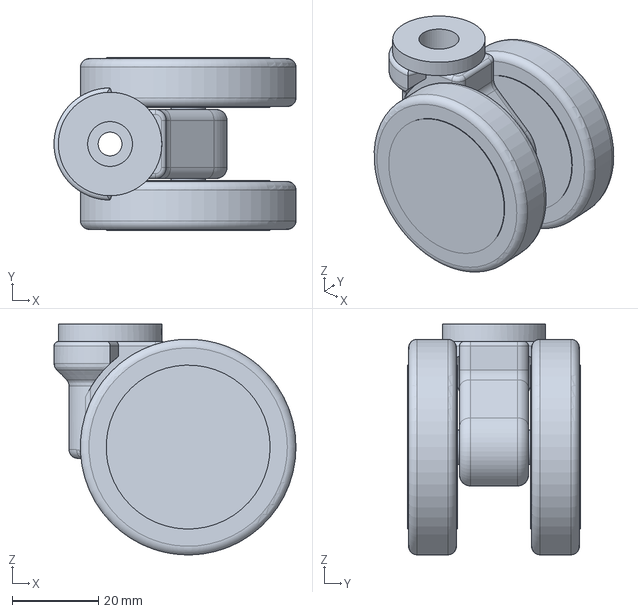
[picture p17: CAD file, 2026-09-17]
export/machined/carriage_fit_proto.step
56.1 x 40.0 x 53.5 mm

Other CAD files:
export/wheel_assembly.step
export/hub.step
export/tire.step
export/spacer.step

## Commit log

2026-09-15 Initial parametric wheel design: Al hub, 2x608, TPU tire
    - build123d model driven by cad/params.py (Ø50x19, Ø8 axle assumed)
    - STEP/STL export, cross-section preview
    - design notes with machinist tolerances, BOM
    - uv-managed project
    [hub.step, spacer.step, tire.step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]
2026-09-15 Add swivel carriage body, through-axle, full assembly
    - body: 18 mm neck between wheels + 34 mm head in front, sculpted to the
    wheel circle; Oilite 10x12x15 bushing bore, AXK1024 thrust stack on top,
    M6 retention counterbore from below
    - single Ø8 h6 axle pin with DIN 471 circlip grooves replaces per-side
    shoulder screws (they would collide in an 18 mm body)
    - analytic clearance report in generate.py
    - orthographic/iso renders (cad/views.py)
    - docs/BOM rewritten for the full carriage; assumed SHOULDER_DEPTH and
    SHAFT_PROTRUSION flagged
    [axle_pin.step, body.step, carriage_assembly.step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]
2026-09-16 Measured envelope: 11.5 mm wheels on 2x688, 17 mm gap, M5 button retention, recess swing check
    - Frame: Z=0 is now the land (recess ceiling); case skin at -22.92, flush
    with the shaft end. Whole shaft + swivel live inside the R47.4 corner recess.
    - Wheels back to the original 11.5 mm width (recess wall caps swing radius);
    hub takes 2x 688 (8x16x5) with a 1.5 mm shoulder instead of 2x 608.
    - Wheel gap 17 (orig 16.63): neck 16, Ø13 counterbore, 1.5 mm wall.
    - Retention: existing M5 button head + nylon Ø12x1.6 washer; Ø10.4 clearance bore.
    - params.py asserts swing radius <= original's; clearance report prints margin.
    - Docs/BOM/README updated; old open questions closed, new ones listed.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
    [axle_pin.step, body.step, carriage_assembly.step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]
2026-09-16 One-piece printable fit proto (body + thrust collar + solid wheels), screws onto the case
    [axle_pin.step, body.step, carriage_assembly.step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]
2026-09-16 Restyle body: round swivel boss with exposed bolt flat, tangent-line arm to a round axle boss
    - Boss: Ø26 about the shaft, half-round in front, tapered into the neck,
    scooped to the wheel circle where it overhangs the wheels. Bottom flat at
    Z -21.1; M5 button head + Ø14 nylon washer sit exposed underneath (no
    counterbore, no thin wall, hex key from below).
    - Arm: Ø18 round about the axle joined to the boss by two tangent lines;
    nothing above the arm, nothing under the bolt head. Body 48 -> 27 g.
    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
    [axle_pin.step, body.step, carriage_assembly.step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]
2026-09-16 Off-the-shelf wheel variant (WHEEL_SOURCE=ots, default): Ø50x12 luggage wheels on a Ø6 axle, trail 16
    - params.py: WHEEL_SOURCE switch; unified WHEEL_W/TREAD_W/INBOARD_T stack;
    Ø6 DIN 471 circlip data; trail 16 keeps the swing radius inside the
    original's (45.9 vs 46.86) with the 13.7-wide bought wheels.
    - wheel.py: OTS wheel + flanged spacer dummies. carriage.py/generate.py branch
    on the variant; machined variant exports to export/machined/.
    - Boss taper moved to x=2 so the wing over the wheel stays >= 1.5 thick.
    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
    [axle_pin.step, body.step, carriage_assembly.step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]
2026-09-16 wheel_sourcing: record unresolved premium leads (Hinomoto, Rimowa Essential, PU-coated bearing rollers)
2026-09-16 wheel_sourcing: Floyd is ~55x19 (measured from photo), 55 mm dual/single trail table, aggressive-inline 55x24 candidates
2026-09-17 Onshape FeatureScript port of the carriage (onshape/carriage.fs); written to the user's document via the Onshape Labs MCP
2026-09-17 Retention: closed bore, OEM style — internal step 0.3 below the shaft end, Ø5.5 bolt hole, M5 head bears on the body; washer dropped
    Applied in params.py/carriage.py, the Onshape FeatureScript (liftFloat/stepT/boltHoleD
    params), design.md, bom.md, README. Fit-check notes: kit axle fits, thrust stack works,
    shaft sat 1.8 proud by design in the previous revision.
    [axle_pin.step, body.step, carriage_assembly.step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]
2026-09-17 onshape: extrude rect/arm/axle-boss separately and union — coincident sketch edges dropped a 15 mm² lens region (quarter-circle hole through the neck)
2026-09-17 DFM/cosmetics: R3 internal corners at the arm junctions, R2.5 arm rounds, R1.5 top round (build123d + FeatureScript); DFM notes for the machinist
    [axle_pin.step, body.step, carriage_assembly.step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]
2026-09-17 Boss becomes a revolved cap: Ø26 band x 6, 45° cone, Ø19 stem; neck rect starts at the axis (no more boxy front); cap/arm/top rounds; ear-side fillets
    - build123d: one-wire plan face (two touching faces extruded as two solids and
    broke the bell intersection); use & not .intersect() (ShapeList -> the scoop
    was silently a no-op); asserts on single-solid results.
    - FeatureScript: opRevolve + INTERSECTION, result body picked up by exclusion;
    cap/stem arc rounds; capT/stemR/capEdgeR params.
    - Interference check body vs wheel envelope = 0. 25.8 g Al.
    [axle_pin.step, body.step, carriage_assembly.step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]
2026-09-17 Retention geometry from the bolt bottoming: head underside 8.5 below shaft end -> flat at -31.12, 7.9 mm step; fix step-ceiling sign (was 0.3 above the shaft end)
    - params: BLIND_DEPTH / BOLT_STICKOUT derived from bolt length; FS: boltStickout param.
    - carriage.py: _try_fillet rejects fillet results whose volume goes the wrong way
    (OCCT returned an inside-out top round that made every later boolean a no-op);
    assert the bushing bore actually removes material.
    - Python 10964 mm3 vs Onshape 10997: agree. Interference vs wheel envelope 0.
    [axle_pin.step, body.step, carriage_assembly.step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]
2026-09-17 onshape: ASCII-only annotations (° broke precondition analysis), flat->flatZ, clear regenError when the arm attachment point is inside the axle boss
